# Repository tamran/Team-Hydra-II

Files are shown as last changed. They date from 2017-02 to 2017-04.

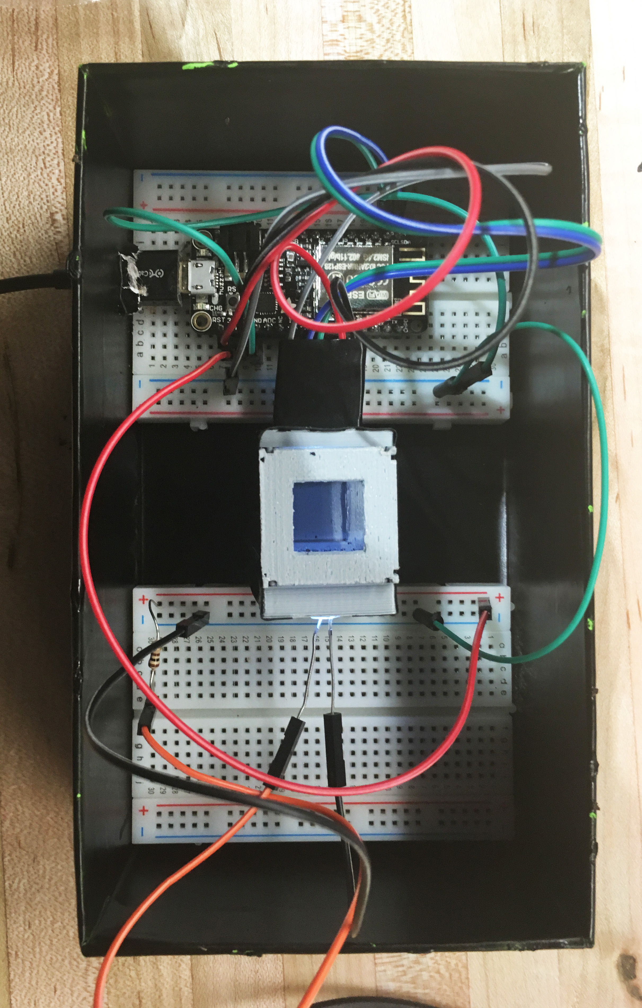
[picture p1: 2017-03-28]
pictures/IMG_0729.png

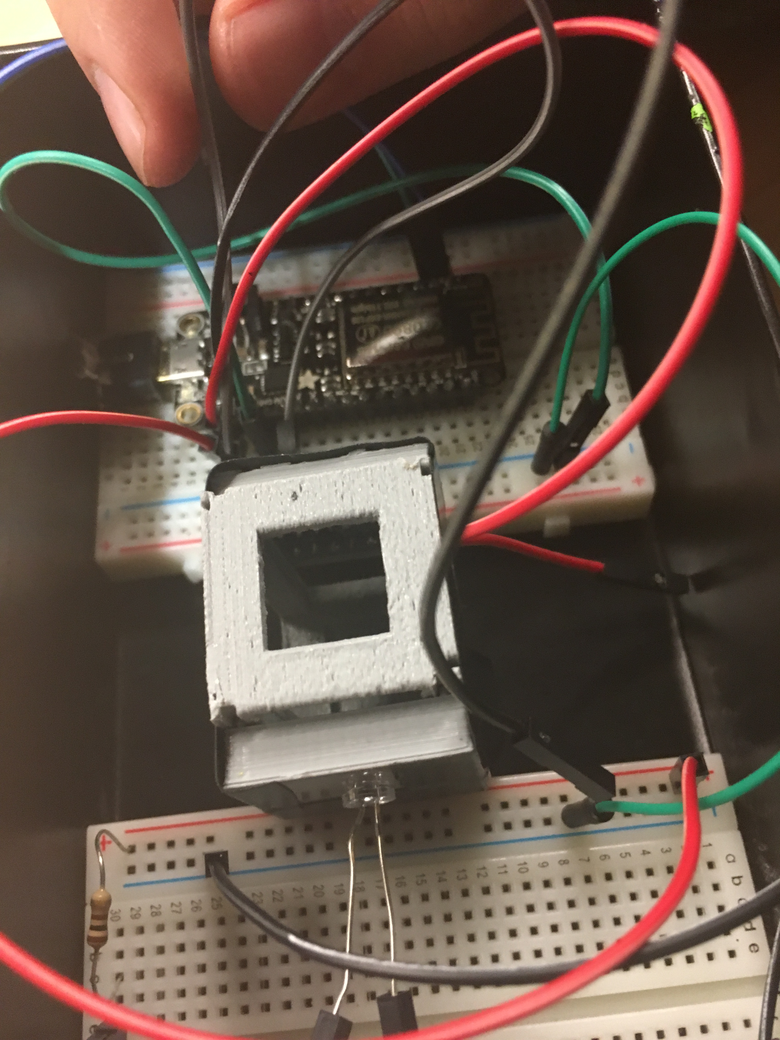
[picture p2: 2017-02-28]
pictures/IMG_0734.JPG

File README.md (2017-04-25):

# Team-Hydra-II

## To access the currently live version of the app:
[Click Here!](https://team-hydra-ii.herokuapp.com/)

## The simplified communication model of this application is:
Application Architecture

## Currently available features on live version:

- From the _web client_
  - Request for a new trial to be started with a given turbidity, concentration, and number of trials
    - __NOTE THAT THE CURRENT MAX NUMBER OF TRIALS IS 30.__ If this number is exceeded, only the first 30 measurements will be posted.
    - This number was chosen as the maximum buffer size that avoids out-of-memory errors
    - _We should run some experiments to see if reducing the measurement frequency will work for our experiments._ If not, we'll need to 1) try to remove any memory leaks in the Arduino code and/or 2) get a microSD for the Feather HUZZAH.
  - View when the last posted measurement was taken
    - __NOTE__ that when the client is first opened, the last posted measurement will be N/A.  When the next measurement is posted to the database, the time will be updated accordingly
  - Clicking the `Experiment Status` navigation item takes you to a page where you can view the new experiment data as it's being added to the database.  This is our equivalent of a "serial monitor." Currently, you can view the Color, Turbidity, and Electrochemical measurements, as they're being taken
  - Clicking the `Trial Data` navigation item displays a list of all conducted Trials.  
    - You can click on the trial name to see all measurements associated with the selected trial.
    - Typing a string into the Filter search box filters the experiments displayed on the screen by the query substring
    - __NOTE__ that the data on this page only updates when you re-select the `Trial Data` navigation item, or when you type a new string
  - Clicking the `Folders` navigation item displays three areas:
    - Create New Folder:
      - Using this field, you can create a new folder in the database
    - Add Trial to Folder:
      - Using this field, you can assoicate a trial in the database with a folder
      - Note that submitting this form will only work correctly if both the folder and trial names already exist in the database
    - Folder Browser:
      - This section displays all folders in the database.  You can filter search for folders.
      - Overall, the purpose of folders is to provide a simple way of associating trials with eachother.  We can mark certain trials as bad by putting them in a "Trash" folder, ect. 

## The server accepts the following API:
  - /
    - `GET` Get the HTML associated with the website
  - /api/newExperiment
    - `GET` Get the information necessary to start running the experiment
      - This is the signal for the sensor to start taking data.  The string will be empty if no experiment is to be run
    - `POST` Inform the server of the information necessary to start running the experiment
      - This API endpoint is intended to be used by the web client
  - /api/clearExperiment
    - `GET` The signal for the sensor to send to the server that it has started to take measurement for the trial specified by /newExperiment
  - /api/trials[?filter=FILTER_STRING]
    - `GET` Returns a string list of the names of all trials stored in the database
      - May optionally filter your request for trials matching a certain string
      - e.g. `/api/trials` returns all trial names
      - e.g. `/api/trials?filter=derp` returns all trials containing the word derp in the trialName
  - /api/trial/:trialName
    - `GET` Returns the measurements associated with the trial :trialName
    - `POST` Creates a trial in the database named :trialName
  - /api/measurement/:type/:trialName
    - `POST` Saves the data stored in the request body to a new measurement in the specified :trialName
      - :type must be one of
        - color
        - turbidity
        - electrochemical
      - When the measurement has been posted to the database, the server notifies the web client that a new measurement has been placed in the database
  - /api/folders[?filter=FILTER_STRING]
    - `GET` returns a string list of the names of all folders stored in the database
  - /api/folder/:folderName
    - `GET` Returns the (unpopulated) Trial objects associated with :folderName
    - `POST` Creates a folder in the database named :folderName
  - /api/folder/:folderName/:trialName
    - `POST` Adds :trialName to the :folderName folder

__NOTE__ that there are two different types of routes - ReactRouter routes, and routes that the server accepts.  For example, there are `/experiment` and `/data` ReactRouter routes that appear when navigating to different tabs on the website. However, reloading the webpage at these routes will result in a _Cannot GET /ROUTE_NAME_.  This is because these are client-side routes only, and thus do not exist on the server side.  I am currently working on a way around this, so that reloading the webpage at one of these routes does not result in the _Cannot GET_ message.

## The (intended) public API available to the Feather

- DataCollection.iso
  - `void collectData(String experiment, int numExperiments)`
    - Takes measurements using the color sensors and the metal rods, and posts the measurements to the database
      - When WiFi isn't available, these measurements are added to a buffer queue, and POSTed when WiFi becomes available again
      - Otherwise, the data is posted as it is collected
      - Note that, in the current setup, each type of measurement is _collected_, but not necessarily _posted_, atomically
        - all of color -> all of turbidity -> all of electrochemical
  - `int createTrial(String trial)`
    - Creates a new trial in the database
    - Returns the HTTP response code (success == 200)
- HTTPRequests.iso
  - `aJsonObject* get(String endpoint)`
    - Makes a GET request to the specified api endpoint
    - Returns the JSON response object
- JSONHelpers.iso
  - `String getField(aJsonObject* json, const char* aField)`
    - Returns the string value of the field in the JSON object
    - Returns "" if the field doesn't exist
  - `aJsonObject* getJson(String response)`
    - Returns the JSON object corresponding to the input string
    - Used to get the JSON object of an HTTP response
  - `aJsonObject* constructMeasurement(const char* R, const char* G, const char* B, const char* C, const char* ColorTemp, const char* lux)`
    - Constructs the JSON object to use as the request for posting a measurement
- WiFiConnector.iso
  - `int connectToWiFi()`
    - Establishes the WiFi connection with our router
    - This command times out after waiting for 5 seconds
    - Returns -1 if could not connect to WiFi, 1 otherwise
    
## Feather Dependencies

In order to run our code, the following packages must be available to the Arduino IDE

- `ESP8266WiFi.h`
- `aJSON.h`
- `ESP8266HTTPClient.h`
- `Adafruit_TCS34725.h`

## Testing Colorimetery *without* the Database
To collect and process colorimetry data **without** pulling from the database, one should run the script `runColorimeter.ino` (under \runColorimeter) in conjunction with the Matlab function `plotCalibData.m.` (under \matlabscripts). 

### Collecting Data
`runColorimeter.ino` allows the Feather to collect *n* data points for each of the color channels. *n* is set in the argument of the function `getColorReading(n)`. Currently *n* is set to 500 but may be modified in the Arduino script. The readings should then be copied from the serial monitor and saved into a text file with the following naming convention: **[type]**Test\_**[val][unit]**.txt where
* **[type]**: 'color' for testing various concentrations; 'turbidity' for testing various turbidities.
* **[val]**: the actual concentration or turbidity of the sample you're testing
* **[unit]**: ppm for concentration, ntu for turbidity

Example: 'colorTest_10ppm.txt'

### Processing in MATLAB
`plotCalibData.m` is a function that analyzes *either* the concentration or turbidity of a set of calibration samples. Given several text files using the naming convention above, it pulls data these text files, and plots the channel measurements against for all of the text files (i.e. samples), and plots the average readings as a function of either concentration or turbidity. The function may be called in the command window of Matlab as follows: `plotCalibData(typeOfTest, values, n)` where
* **typeOfTest**: 'color' if you are analyzing calibration samples of different concentrations; 'turbidity' if you are analyzing calibration samples of different turbidities.
* **values**: vector of concentrations or turbidities you would like to analyze. (e.g. [1, 10, 20, 30, 40] where each number represents the concentration in ppm)
* **n**: number of data points contained in each sample trial/text file.

## To setup the Feather communication in Arduino:

- host = team-hydra-ii.herokuapp.com
- httpPort = 80
- Check for a new measurement
  - Make a GET request to /api/newMeasurement
  - If the response has a body (i.e. is not {})
    - Make a POST request to /api/trial/:trialName (where :trialName is the `experimentName` field in the response body of the previous GET request) to create a new trial called :trialName in the database
    - The number of times to run the experiment is specified in the response body of the GET request, in the field `numExperiments`
    - For each measurement that you take, make a POST request to /api/measurement/color/:trialName, where the body of the post request contains all of the measurement information
    - Once the requested number of measurements have been taken, make a GET request to /api/clearExperiment to clear the requested experiment that you just completed
    
## To communicate with the API over command line:

- To create a new experiment:
  - Go to the website, fill out the form, and press enter
- To view the new experiment that is created by the form on the website:
  - `curl team-hydra-ii.herokuapp.com/api/newExperiment`
- To create a new trial in the database:
  - `curl --data "" team-hydra-ii.herokuapp.com/api/trial/TRIALNAME`
- To add a measurement to this trial name:
  - `curl --data "R=2&G=3&B=4&C=5&ColorTemp=6&lux=7" team-hydra-ii.herokuapp.com/api/measurement/color/TRIALNAME`
- To clear the new experiment flag once the experiment has completed:
  - `curl team-hydra-ii.herokuapp.com/api/clearExperiment`

## To setup the Express Server on a local machine:

- First, you'll need to install [NodeJS](https://nodejs.org/en/)
- Navigate to the base directory of the Team-Hydra-II project
- Type `npm install` to install all dependencies listed in `package.json`

## To start the app locally:

- Run `npm run watch` to transpile the client-side code into a form that can be rendered in a browser
- Run `npm run serve` to start the development server
  - **Important** this command will __fail__ unless you have initialized the MONGODB_URI environment variable
  - I have intentionally hidden this, as keeping this under version control is *very* bad practice (for obvious reasons).
  - If you need to run this server in development, let me know, and I'll give you access to this URI
- To open the app locally, go to a browser and visit `localhost:3000`.
- The setup allows continuous development without re-running code!
  - __Note__ that when you make changes to files in the `server/` directory, the server will automatically be restarted with nodemon.   When you change code in the `src/` directory, the code will be re-transpiled with watchify and babelify

## To prepare the app for production:
- Run `npm run build`
  - This builds a production-ready, transpiled server and client code that can be run on Heroku. 
  - This is necessary, as I'm using new JavaScript syntax, and node does not currently support all of its features
- Commit/push all changes, then upload to Heroku using `git push heroku master`
- You can then visit the live website by typing `heroku open` in terminal

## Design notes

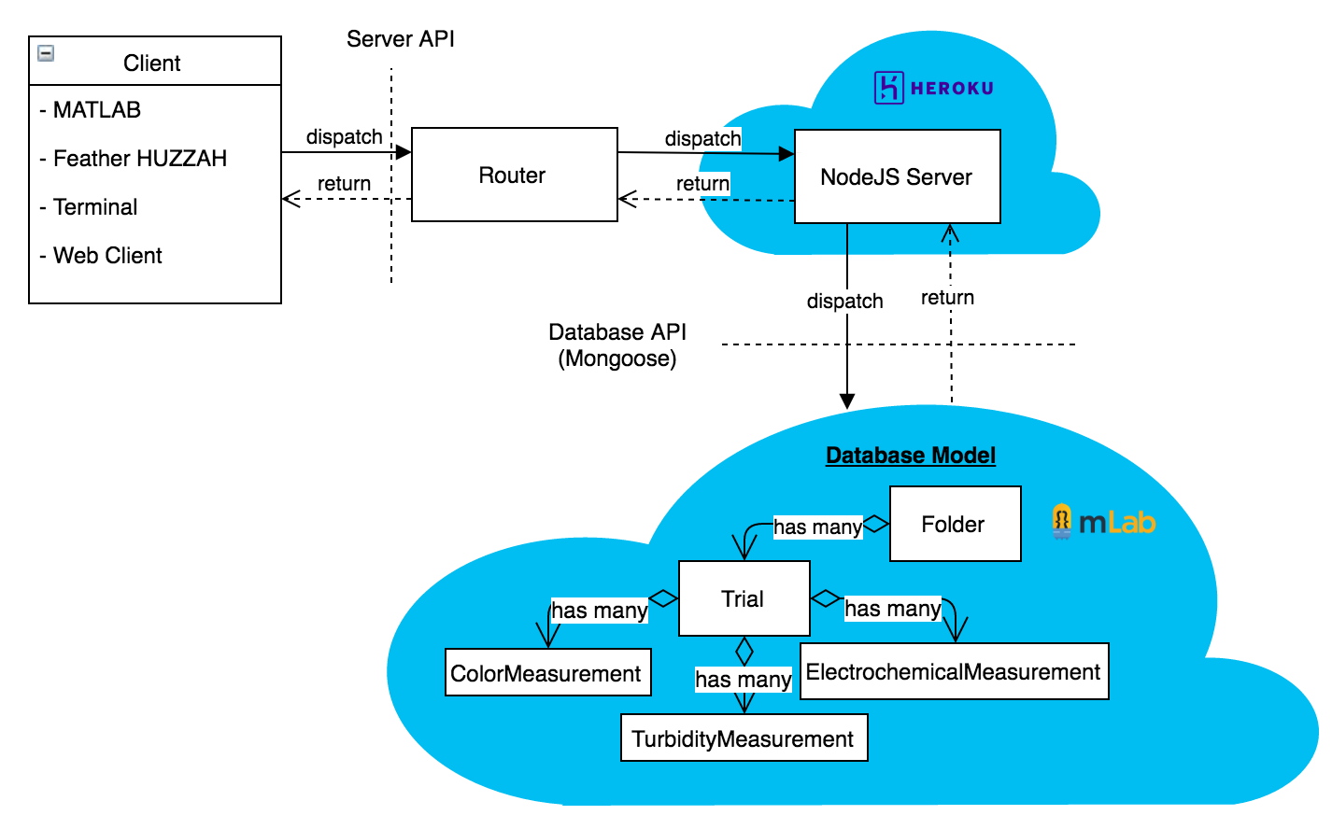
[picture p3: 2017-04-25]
diagrams/UpdateAppArchitecture2.png

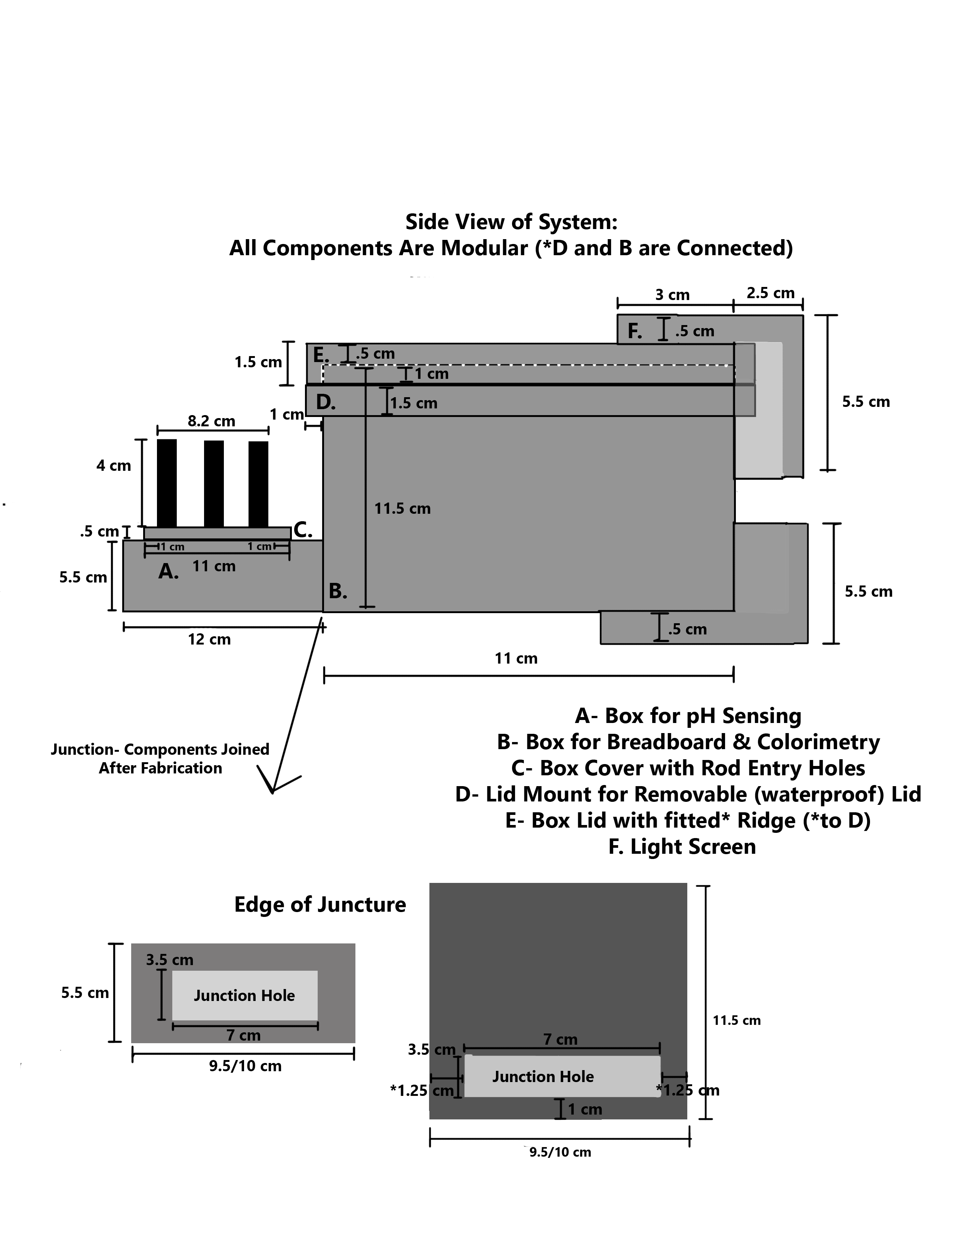
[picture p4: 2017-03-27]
PhotoshopFiles/GeneralCasingDesign.png

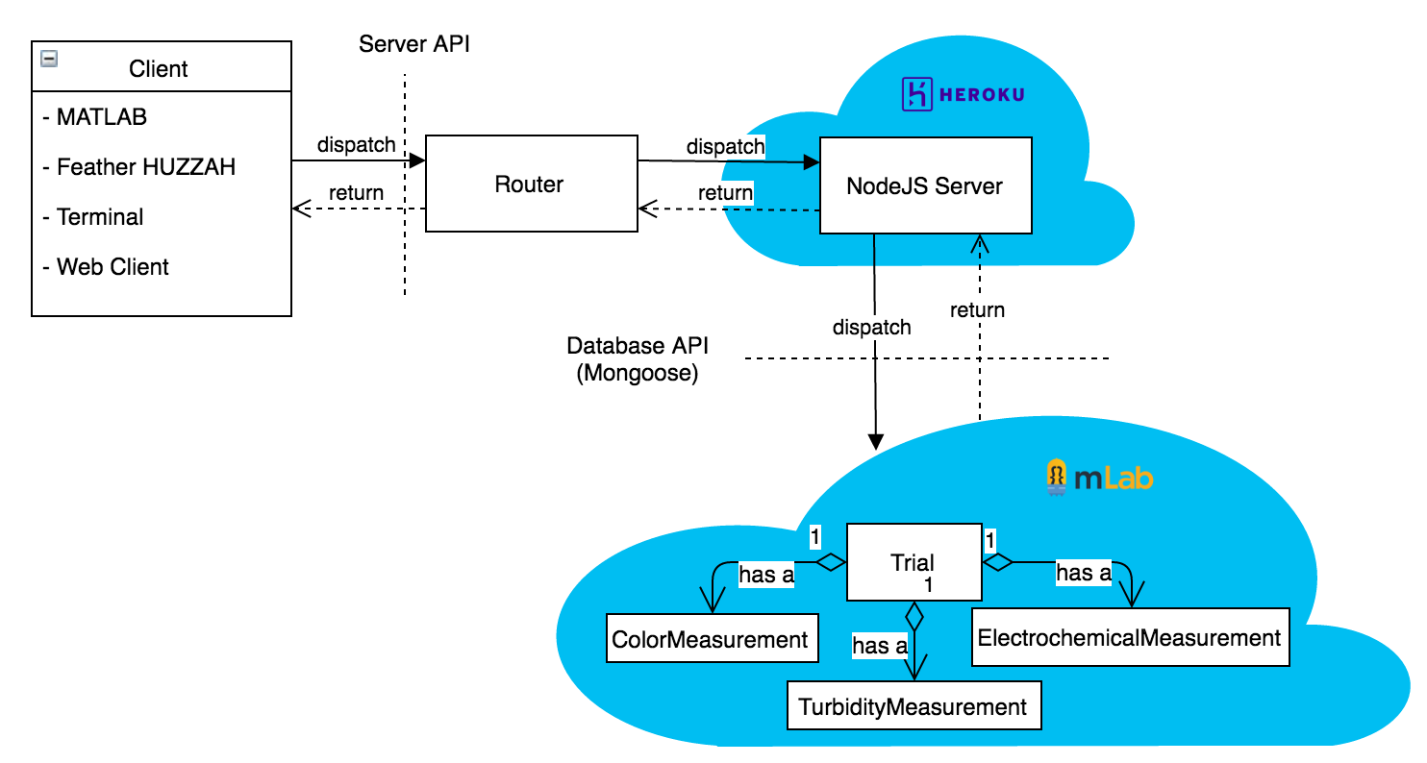
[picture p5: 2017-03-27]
diagrams/AppArchitecture.png

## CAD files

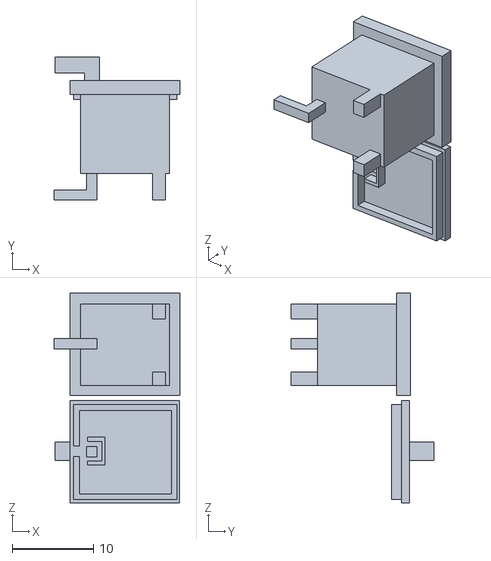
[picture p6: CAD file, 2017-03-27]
autocad_files/ColorimeterModel.stl
15.5 x 17.6 x 25.9

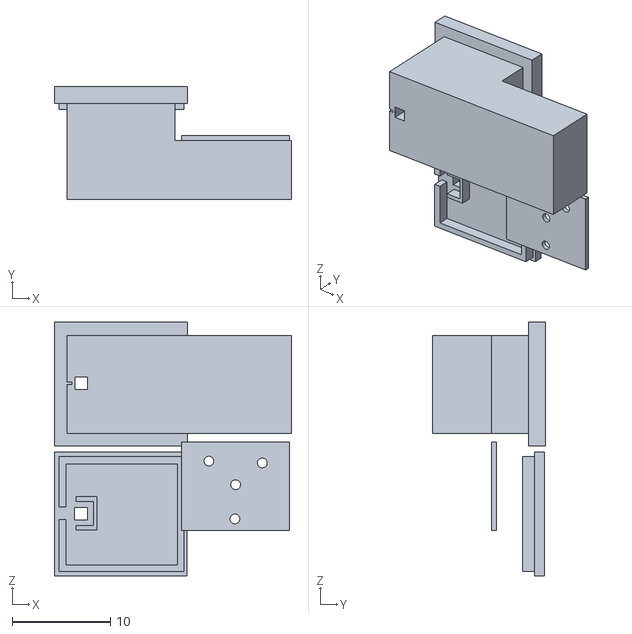
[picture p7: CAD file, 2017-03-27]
autocad_files/PrototypeMarch21.stl
24.2 x 11.5 x 25.9

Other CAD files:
autocad_files/SensorHolder.dwg
autocad_files/LEDHolder.dwg
autocad_files/SampleHolder.dwg

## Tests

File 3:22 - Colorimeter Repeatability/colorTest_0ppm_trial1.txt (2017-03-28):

Color Temp: 17456 K - Lux: 2768 - R: 3915 G: 5235 B: 5770 C: 15007  
Color Temp: 17512 K - Lux: 2765 - R: 3914 G: 5234 B: 5772 C: 15007  
Color Temp: 17532 K - Lux: 2765 - R: 3913 G: 5234 B: 5773 C: 15008  
Color Temp: 17550 K - Lux: 2764 - R: 3913 G: 5234 B: 5774 C: 15009  
Color Temp: 17552 K - Lux: 2764 - R: 3912 G: 5233 B: 5773 C: 15006  
Color Temp: 17570 K - Lux: 2764 - R: 3912 G: 5234 B: 5775 C: 15009  
Color Temp: 17570 K - Lux: 2764 - R: 3912 G: 5234 B: 5775 C: 15008  
Color Temp: 17593 K - Lux: 2762 - R: 3910 G: 5232 B: 5774 C: 15003  
Color Temp: 17607 K - Lux: 2762 - R: 3912 G: 5233 B: 5776 C: 15008  
Color Temp: 17609 K - Lux: 2762 - R: 3911 G: 5233 B: 5776 C: 15008  
Color Temp: 17606 K - Lux: 2762 - R: 3912 G: 5234 B: 5777 C: 15010  
Color Temp: 17609 K - Lux: 2762 - R: 3911 G: 5233 B: 5776 C: 15008  
Color Temp: 17624 K - Lux: 2762 - R: 3912 G: 5234 B: 5778 C: 15012  
Color Temp: 17624 K - Lux: 2762 - R: 3912 G: 5235 B: 5779 C: 15014  
Color Temp: 17624 K - Lux: 2762 - R: 3912 G: 5234 B: 5778 C: 15011  
Color Temp: 17627 K - Lux: 2761 - R: 3911 G: 5233 B: 5777 C: 15009  
Color Temp: 17650 K - Lux: 2759 - R: 3909 G: 5231 B: 5776 C: 15003  
Color Temp: 17650 K - Lux: 2759 - R: 3909 G: 5231 B: 5776 C: 15003  
Color Temp: 17652 K - Lux: 2759 - R: 3908 G: 5230 B: 5775 C: 15001  
Color Temp: 17655 K - Lux: 2757 - R: 3907 G: 5228 B: 5773 C: 14997  
Color Temp: 17655 K - Lux: 2757 - R: 3907 G: 5228 B: 5773 C: 14997  
Color Temp: 17653 K - Lux: 2758 - R: 3908 G: 5229 B: 5774 C: 14999  
Color Temp: 17671 K - Lux: 2757 - R: 3908 G: 5229 B: 5775 C: 15000  
Color Temp: 17673 K - Lux: 2757 - R: 3907 G: 5228 B: 5774 C: 14997  
Color Temp: 17655 K - Lux: 2757 - R: 3907 G: 5228 B: 5773 C: 14996  
Color Temp: 17670 K - Lux: 2758 - R: 3908 G: 5230 B: 5776 C: 15001  
Color Temp: 17673 K - Lux: 2757 - R: 3907 G: 5228 B: 5774 C: 14997  
Color Temp: 17654 K - Lux: 2758 - R: 3907 G: 5229 B: 5774 C: 14997  
Color Temp: 17676 K - Lux: 2756 - R: 3906 G: 5227 B: 5773 C: 14992  
Color Temp: 17657 K - Lux: 2758 - R: 3906 G: 5228 B: 5773 C: 14993  
Color Temp: 17673 K - Lux: 2757 - R: 3907 G: 5228 B: 5774 C: 14995  
Color Temp: 17676 K - Lux: 2756 - R: 3906 G: 5227 B: 5773 C: 14992  
Color Temp: 17678 K - Lux: 2756 - R: 3905 G: 5226 B: 5772 C: 14989  
Color Temp: 17680 K - Lux: 2755 - R: 3904 G: 5225 B: 5771 C: 14985  
Color Temp: 17686 K - Lux: 2753 - R: 3902 G: 5222 B: 5768 C: 14978  
Color Temp: 17688 K - Lux: 2753 - R: 3901 G: 5221 B: 5767 C: 14976  
Color Temp: 17696 K - Lux: 2755 - R: 3905 G: 5226 B: 5773 C: 14991  
Color Temp: 17696 K - Lux: 2755 - R: 3905 G: 5226 B: 5773 C: 14992  
Color Temp: 17688 K - Lux: 2753 - R: 3901 G: 5221 B: 5767 C: 14976  
Color Temp: 17691 K - Lux: 2751 - R: 3900 G: 5219 B: 5765 C: 14971  
Color Temp: 17712 K - Lux: 2750 - R: 3899 G: 5218 B: 5765 C: 14969  
Color Temp: 17693 K - Lux: 2752 - R: 3899 G: 5219 B: 5765 C: 14970  
Color Temp: 17709 K - Lux: 2751 - R: 3900 G: 5219 B: 5766 C: 14972  
Color Temp: 17711 K - Lux: 2751 - R: 3899 G: 5219 B: 5766 C: 14971  
Color Temp: 17693 K - Lux: 2752 - R: 3899 G: 5219 B: 5765 C: 14970  
Color Temp: 17709 K - Lux: 2751 - R: 3900 G: 5220 B: 5767 C: 14974  
Color Temp: 17712 K - Lux: 2750 - R: 3899 G: 5218 B: 5765 C: 14969  
Color Temp: 17695 K - Lux: 2751 - R: 3898 G: 5218 B: 5764 C: 14967  
Color Temp: 17715 K - Lux: 2749 - R: 3898 G: 5216 B: 5763 C: 14964  
Color Temp: 17701 K - Lux: 2749 - R: 3896 G: 5215 B: 5761 C: 14960  
Color Temp: 17701 K - Lux: 2748 - R: 3896 G: 5214 B: 5760 C: 14958  
Color Temp: 17719 K - Lux: 2748 - R: 3896 G: 5214 B: 5761 C: 14957  
Color Temp: 17708 K - Lux: 2747 - R: 3893 G: 5211 B: 5757 C: 14947  
Color Temp: 17711 K - Lux: 2746 - R: 3892 G: 5210 B: 5756 C: 14945  
Color Temp: 17692 K - Lux: 2747 - R: 3892 G: 5210 B: 5755 C: 14943  
Color Temp: 17695 K - Lux: 2747 - R: 3891 G: 5209 B: 5754 C: 14940  
Color Temp: 17713 K - Lux: 2746 - R: 3891 G: 5209 B: 5755 C: 14940  
Color Temp: 17713 K - Lux: 2746 - R: 3891 G: 5209 B: 5755 C: 14940  
Color Temp: 17708 K - Lux: 2748 - R: 3893 G: 5212 B: 5758 C: 14947  
Color Temp: 17727 K - Lux: 2746 - R: 3893 G: 5211 B: 5758 C: 14946  
Color Temp: 17727 K - Lux: 2745 - R: 3893 G: 5210 B: 5757 C: 14945  
Color Temp: 17711 K - Lux: 2746 - R: 3892 G: 5209 B: 5755 C: 14942  
Color Temp: 17713 K - Lux: 2746 - R: 3891 G: 5209 B: 5755 C: 14941  
Color Temp: 17710 K - Lux: 2747 - R: 3892 G: 5211 B: 5757 C: 14945  
Color Temp: 17711 K - Lux: 2746 - R: 3892 G: 5210 B: 5756 C: 14944  
Color Temp: 17713 K - Lux: 2746 - R: 3891 G: 5209 B: 5755 C: 14941  
Color Temp: 17718 K - Lux: 2745 - R: 3889 G: 5207 B: 5753 C: 14936  
Color Temp: 17724 K - Lux: 2742 - R: 3887 G: 5203 B: 5749 C: 14925  
Color Temp: 17710 K - Lux: 2742 - R: 3885 G: 5201 B: 5746 C: 14918  
Color Temp: 17713 K - Lux: 2740 - R: 3884 G: 5199 B: 5744 C: 14913  
Color Temp: 17705 K - Lux: 2738 - R: 3880 G: 5194 B: 5738 C: 14900  
Color Temp: 17710 K - Lux: 2736 - R: 3878 G: 5191 B: 5735 C: 14893  
Color Temp: 17715 K - Lux: 2735 - R: 3876 G: 5189 B: 5733 C: 14886  
Color Temp: 17739 K - Lux: 2733 - R: 3874 G: 5186 B: 5731 C: 14879  
Color Temp: 17742 K - Lux: 2731 - R: 3873 G: 5184 B: 5729 C: 14874  
Color Temp: 17744 K - Lux: 2731 - R: 3872 G: 5183 B: 5728 C: 14871  
Color Temp: 17744 K - Lux: 2731 - R: 3872 G: 5183 B: 5728 C: 14871  
Color Temp: 17728 K - Lux: 2731 - R: 3871 G: 5182 B: 5726 C: 14865  
Color Temp: 17731 K - Lux: 2730 - R: 3870 G: 5180 B: 5724 C: 14859  
Color Temp: 17736 K - Lux: 2729 - R: 3868 G: 5178 B: 5722 C: 14855  
Color Temp: 17739 K - Lux: 2727 - R: 3867 G: 5176 B: 5720 C: 14850  
Color Temp: 17723 K - Lux: 2727 - R: 3866 G: 5175 B: 5718 C: 14846  
Color Temp: 17744 K - Lux: 2725 - R: 3865 G: 5173 B: 5717 C: 14842  
Color Temp: 17749 K - Lux: 2724 - R: 3863 G: 5171 B: 5715 C: 14836  
Color Temp: 17731 K - Lux: 2725 - R: 3863 G: 5171 B: 5714 C: 14834  
Color Temp: 17733 K - Lux: 2724 - R: 3862 G: 5170 B: 5713 C: 14831  
Color Temp: 17733 K - Lux: 2724 - R: 3862 G: 5170 B: 5713 C: 14831  
Color Temp: 17736 K - Lux: 2724 - R: 3861 G: 5169 B: 5712 C: 14829  
Color Temp: 17741 K - Lux: 2722 - R: 3859 G: 5166 B: 5709 C: 14820  
Color Temp: 17743 K - Lux: 2722 - R: 3858 G: 5165 B: 5708 C: 14818  
Color Temp: 17744 K - Lux: 2721 - R: 3858 G: 5164 B: 5707 C: 14815  
Color Temp: 17749 K - Lux: 2720 - R: 3856 G: 5162 B: 5705 C: 14808  
Color Temp: 17733 K - Lux: 2720 - R: 3855 G: 5161 B: 5703 C: 14804  
Color Temp: 17737 K - Lux: 2719 - R: 3853 G: 5159 B: 5701 C: 14798  
Color Temp: 17738 K - Lux: 2718 - R: 3853 G: 5158 B: 5700 C: 14796  
Color Temp: 17740 K - Lux: 2717 - R: 3852 G: 5157 B: 5699 C: 14793  
Color Temp: 17724 K - Lux: 2718 - R: 3851 G: 5156 B: 5697 C: 14788  
Color Temp: 17751 K - Lux: 2714 - R: 3848 G: 5152 B: 5694 C: 14779  
Color Temp: 17737 K - Lux: 2714 - R: 3846 G: 5150 B: 5691 C: 14772  
Color Temp: 17742 K - Lux: 2712 - R: 3844 G: 5147 B: 5688 C: 14765  
Color Temp: 17745 K - Lux: 2711 - R: 3843 G: 5145 B: 5686 C: 14760  
Color Temp: 17748 K - Lux: 2710 - R: 3842 G: 5143 B: 5684 C: 14754  
Color Temp: 17751 K - Lux: 2709 - R: 3841 G: 5142 B: 5683 C: 14750  
Color Temp: 17772 K - Lux: 2708 - R: 3840 G: 5141 B: 5683 C: 14749  
Color Temp: 17736 K - Lux: 2710 - R: 3839 G: 5141 B: 5681 C: 14746  
Color Temp: 17734 K - Lux: 2710 - R: 3840 G: 5142 B: 5682 C: 14749  
Color Temp: 17756 K - Lux: 2708 - R: 3839 G: 5140 B: 5681 C: 14745  
Color Temp: 17756 K - Lux: 2708 - R: 3839 G: 5140 B: 5681 C: 14746  
Color Temp: 17756 K - Lux: 2708 - R: 3839 G: 5140 B: 5681 C: 14746  
Color Temp: 17753 K - Lux: 2708 - R: 3840 G: 5141 B: 5682 C: 14749  
Color Temp: 17751 K - Lux: 2709 - R: 3841 G: 5142 B: 5683 C: 14751  
Color Temp: 17751 K - Lux: 2709 - R: 3841 G: 5142 B: 5683 C: 14751  
Color Temp: 17734 K - Lux: 2710 - R: 3840 G: 5142 B: 5682 C: 14749  
Color Temp: 17734 K - Lux: 2710 - R: 3840 G: 5142 B: 5682 C: 14749  
Color Temp: 17742 K - Lux: 2708 - R: 3837 G: 5138 B: 5678 C: 14738  
Color Temp: 17742 K - Lux: 2708 - R: 3837 G: 5138 B: 5678 C: 14738  
Color Temp: 17745 K - Lux: 2706 - R: 3836 G: 5136 B: 5676 C: 14733  
Color Temp: 17729 K - Lux: 2707 - R: 3835 G: 5135 B: 5674 C: 14728  
Color Temp: 17731 K - Lux: 2706 - R: 3834 G: 5134 B: 5673 C: 14726  
Color Temp: 17753 K - Lux: 2704 - R: 3833 G: 5132 B: 5672 C: 14723  
Color Temp: 17753 K - Lux: 2704 - R: 3833 G: 5132 B: 5672 C: 14722  
Color Temp: 17753 K - Lux: 2703 - R: 3833 G: 5131 B: 5671 C: 14721  
Color Temp: 17758 K - Lux: 2702 - R: 3831 G: 5129 B: 5669 C: 14715  
Color Temp: 17760 K - Lux: 2702 - R: 3830 G: 5129 B: 5669 C: 14713  
Color Temp: 17763 K - Lux: 2701 - R: 3829 G: 5127 B: 5667 C: 14708  
Color Temp: 17763 K - Lux: 2701 - R: 3829 G: 5127 B: 5667 C: 14708  
Color Temp: 17761 K - Lux: 2701 - R: 3830 G: 5128 B: 5668 C: 14710  
Color Temp: 17763 K - Lux: 2701 - R: 3829 G: 5127 B: 5667 C: 14708  
Color Temp: 17761 K - Lux: 2701 - R: 3830 G: 5128 B: 5668 C: 14710  
Color Temp: 17739 K - Lux: 2704 - R: 3831 G: 5130 B: 5669 C: 14716  
Color Temp: 17758 K - Lux: 2703 - R: 3831 G: 5130 B: 5670 C: 14716  
Color Temp: 17761 K - Lux: 2701 - R: 3830 G: 5128 B: 5668 C: 14711  
Color Temp: 17750 K - Lux: 2700 - R: 3827 G: 5124 B: 5663 C: 14698  
Color Temp: 17755 K - Lux: 2698 - R: 3825 G: 5121 B: 5660 C: 14690  
Color Temp: 17760 K - Lux: 2697 - R: 3823 G: 5119 B: 5658 C: 14685  
Color Temp: 17761 K - Lux: 2696 - R: 3823 G: 5118 B: 5657 C: 14683  
Color Temp: 17761 K - Lux: 2696 - R: 3823 G: 5118 B: 5657 C: 14683  
Color Temp: 17766 K - Lux: 2695 - R: 3821 G: 5116 B: 5655 C: 14677  
Color Temp: 17766 K - Lux: 2695 - R: 3821 G: 5116 B: 5655 C: 14676  
Color Temp: 17755 K - Lux: 2698 - R: 3825 G: 5121 B: 5660 C: 14692  
Color Temp: 17764 K - Lux: 2706 - R: 3836 G: 5136 B: 5677 C: 14735  
Color Temp: 17764 K - Lux: 2706 - R: 3836 G: 5136 B: 5677 C: 14734  
Color Temp: 17772 K - Lux: 2712 - R: 3847 G: 5150 B: 5693 C: 14775  
Color Temp: 17756 K - Lux: 2713 - R: 3846 G: 5150 B: 5692 C: 14774  
Color Temp: 17772 K - Lux: 2712 - R: 3847 G: 5150 B: 5693 C: 14775  
Color Temp: 17758 K - Lux: 2713 - R: 3845 G: 5149 B: 5691 C: 14770  
Color Temp: 17759 K - Lux: 2712 - R: 3845 G: 5148 B: 5690 C: 14767  
Color Temp: 17764 K - Lux: 2711 - R: 3843 G: 5146 B: 5688 C: 14762  
Color Temp: 17767 K - Lux: 2710 - R: 3842 G: 5144 B: 5686 C: 14757  
Color Temp: 17755 K - Lux: 2709 - R: 3839 G: 5141 B: 5682 C: 14748  
Color Temp: 17747 K - Lux: 2706 - R: 3835 G: 5135 B: 5675 C: 14730  
Color Temp: 17755 K - Lux: 2704 - R: 3832 G: 5132 B: 5672 C: 14722  
Color Temp: 17774 K - Lux: 2703 - R: 3832 G: 5131 B: 5672 C: 14720  
Color Temp: 17757 K - Lux: 2704 - R: 3831 G: 5131 B: 5671 C: 14717  
Color Temp: 17758 K - Lux: 2703 - R: 3831 G: 5130 B: 5670 C: 14717  
Color Temp: 17758 K - Lux: 2703 - R: 3831 G: 5130 B: 5670 C: 14716  
Color Temp: 17777 K - Lux: 2701 - R: 3831 G: 5129 B: 5670 C: 14714  
Color Temp: 17758 K - Lux: 2702 - R: 3831 G: 5129 B: 5669 C: 14714  
Color Temp: 17760 K - Lux: 2702 - R: 3830 G: 5129 B: 5669 C: 14714  
Color Temp: 17763 K - Lux: 2701 - R: 3829 G: 5127 B: 5667 C: 14707  
Color Temp: 17763 K - Lux: 2702 - R: 3829 G: 5128 B: 5668 C: 14707  
Color Temp: 17763 K - Lux: 2701 - R: 3829 G: 5127 B: 5667 C: 14706  
Color Temp: 17746 K - Lux: 2702 - R: 3828 G: 5127 B: 5666 C: 14704  
Color Temp: 17730 K - Lux: 2702 - R: 3827 G: 5126 B: 5664 C: 14701  
Color Temp: 17752 K - Lux: 2700 - R: 3826 G: 5124 B: 5663 C: 14697  
Color Temp: 17771 K - Lux: 2699 - R: 3826 G: 5123 B: 5663 C: 14698  
Color Temp: 17769 K - Lux: 2699 - R: 3827 G: 5124 B: 5664 C: 14700  
Color Temp: 17766 K - Lux: 2700 - R: 3828 G: 5126 B: 5666 C: 14705  
Color Temp: 17760 K - Lux: 2702 - R: 3830 G: 5129 B: 5669 C: 14712  
Color Temp: 17755 K - Lux: 2703 - R: 3832 G: 5131 B: 5671 C: 14718  
Color Temp: 17755 K - Lux: 2704 - R: 3832 G: 5132 B: 5672 C: 14721  
Color Temp: 17752 K - Lux: 2705 - R: 3833 G: 5133 B: 5673 C: 14722  
Color Temp: 17752 K - Lux: 2705 - R: 3833 G: 5133 B: 5673 C: 14723  
Color Temp: 17752 K - Lux: 2705 - R: 3833 G: 5133 B: 5673 C: 14723  
Color Temp: 17755 K - Lux: 2704 - R: 3832 G: 5132 B: 5672 C: 14720  
Color Temp: 17772 K - Lux: 2703 - R: 3833 G: 5132 B: 5673 C: 14722  
Color Temp: 17771 K - Lux: 2704 - R: 3833 G: 5133 B: 5674 C: 14725  
Color Temp: 17766 K - Lux: 2705 - R: 3835 G: 5135 B: 5676 C: 14729  
Color Temp: 17766 K - Lux: 2705 - R: 3835 G: 5135 B: 5676 C: 14729  
Color Temp: 17747 K - Lux: 2707 - R: 3835 G: 5136 B: 5676 C: 14730  
Color Temp: 17763 K - Lux: 2706 - R: 3836 G: 5137 B: 5678 C: 14735  
Color Temp: 17761 K - Lux: 2707 - R: 3837 G: 5138 B: 5679 C: 14737  
Color Temp: 17758 K - Lux: 2707 - R: 3838 G: 5139 B: 5680 C: 14742  
Color Temp: 17778 K - Lux: 2706 - R: 3838 G: 5138 B: 5680 C: 14743  
Color Temp: 17759 K - Lux: 2707 - R: 3838 G: 5138 B: 5679 C: 14742  
Color Temp: 17779 K - Lux: 2706 - R: 3837 G: 5138 B: 5680 C: 14740  
Color Temp: 17778 K - Lux: 2706 - R: 3838 G: 5138 B: 5680 C: 14743  
Color Temp: 17758 K - Lux: 2707 - R: 3838 G: 5139 B: 5680 C: 14742  
Color Temp: 17761 K - Lux: 2707 - R: 3837 G: 5138 B: 5679 C: 14739  
Color Temp: 17764 K - Lux: 2706 - R: 3836 G: 5136 B: 5677 C: 14735  
Color Temp: 17785 K - Lux: 2703 - R: 3835 G: 5134 B: 5676 C: 14732  
Color Temp: 17767 K - Lux: 2704 - R: 3835 G: 5134 B: 5675 C: 14731  
Color Temp: 17788 K - Lux: 2703 - R: 3834 G: 5133 B: 5675 C: 14730  
Color Temp: 17772 K - Lux: 2703 - R: 3833 G: 5132 B: 5673 C: 14724  
Color Temp: 17755 K - Lux: 2703 - R: 3832 G: 5131 B: 5671 C: 14720  
Color Temp: 17763 K - Lux: 2702 - R: 3829 G: 5128 B: 5668 C: 14711  
Color Temp: 17780 K - Lux: 2701 - R: 3830 G: 5128 B: 5669 C: 14712  
Color Temp: 17780 K - Lux: 2701 - R: 3830 G: 5128 B: 5669 C: 14711  
Color Temp: 17780 K - Lux: 2701 - R: 3830 G: 5128 B: 5669 C: 14712  
Color Temp: 17781 K - Lux: 2701 - R: 3829 G: 5128 B: 5669 C: 14711  
Color Temp: 17782 K - Lux: 2700 - R: 3829 G: 5127 B: 5668 C: 14708  
Color Temp: 17763 K - Lux: 2702 - R: 3829 G: 5128 B: 5668 C: 14708  
Color Temp: 17766 K - Lux: 2700 - R: 3828 G: 5126 B: 5666 C: 14703  
Color Temp: 17768 K - Lux: 2700 - R: 3827 G: 5125 B: 5665 C: 14702  
Color Temp: 17771 K - Lux: 2699 - R: 3826 G: 5123 B: 5663 C: 14697  
Color Temp: 17752 K - Lux: 2700 - R: 3826 G: 5124 B: 5663 C: 14697  
Color Temp: 17754 K - Lux: 2700 - R: 3825 G: 5123 B: 5662 C: 14695  
Color Temp: 17776 K - Lux: 2697 - R: 3824 G: 5121 B: 5661 C: 14691  
Color Temp: 17774 K - Lux: 2698 - R: 3825 G: 5122 B: 5662 C: 14693  
Color Temp: 17791 K - Lux: 2697 - R: 3826 G: 5122 B: 5663 C: 14696  
Color Temp: 17774 K - Lux: 2698 - R: 3825 G: 5122 B: 5662 C: 14694  
Color Temp: 17752 K - Lux: 2699 - R: 3826 G: 5123 B: 5662 C: 14696  
Color Temp: 17774 K - Lux: 2698 - R: 3825 G: 5122 B: 5662 C: 14694  
Color Temp: 17755 K - Lux: 2699 - R: 3825 G: 5122 B: 5661 C: 14694  
Color Temp: 17755 K - Lux: 2699 - R: 3825 G: 5122 B: 5661 C: 14693  
Color Temp: 17774 K - Lux: 2698 - R: 3825 G: 5122 B: 5662 C: 14696  
Color Temp: 17774 K - Lux: 2698 - R: 3825 G: 5122 B: 5662 C: 14695  
Color Temp: 17793 K - Lux: 2696 - R: 3825 G: 5121 B: 5662 C: 14693  
Color Temp: 17776 K - Lux: 2697 - R: 3824 G: 5121 B: 5661 C: 14691  
Color Temp: 17779 K - Lux: 2696 - R: 3823 G: 5119 B: 5659 C: 14687  
Color Temp: 17799 K - Lux: 2695 - R: 3823 G: 5118 B: 5659 C: 14685  
Color Temp: 17779 K - Lux: 2697 - R: 3823 G: 5120 B: 5660 C: 14688  
Color Temp: 17796 K - Lux: 2696 - R: 3824 G: 5120 B: 5661 C: 14690  
Color Temp: 17774 K - Lux: 2698 - R: 3825 G: 5122 B: 5662 C: 14693  
Color Temp: 17773 K - Lux: 2699 - R: 3825 G: 5123 B: 5663 C: 14696  
Color Temp: 17774 K - Lux: 2698 - R: 3825 G: 5122 B: 5662 C: 14694  
Color Temp: 17793 K - Lux: 2696 - R: 3825 G: 5121 B: 5662 C: 14693  
Color Temp: 17774 K - Lux: 2698 - R: 3825 G: 5122 B: 5662 C: 14695  
Color Temp: 17773 K - Lux: 2699 - R: 3825 G: 5123 B: 5663 C: 14697  
Color Temp: 17771 K - Lux: 2699 - R: 3826 G: 5123 B: 5663 C: 14698  
Color Temp: 17787 K - Lux: 2699 - R: 3827 G: 5125 B: 5666 C: 14704  
Color Temp: 17766 K - Lux: 2700 - R: 3828 G: 5126 B: 5666 C: 14705  
Color Temp: 17782 K - Lux: 2700 - R: 3829 G: 5127 B: 5668 C: 14709  
Color Temp: 17763 K - Lux: 2702 - R: 3829 G: 5128 B: 5668 C: 14711  
Color Temp: 17778 K - Lux: 2702 - R: 3830 G: 5130 B: 5671 C: 14716  
Color Temp: 17774 K - Lux: 2703 - R: 3832 G: 5132 B: 5673 C: 14723  
Color Temp: 17774 K - Lux: 2703 - R: 3832 G: 5132 B: 5673 C: 14723  
Color Temp: 17790 K - Lux: 2702 - R: 3833 G: 5132 B: 5674 C: 14725  
Color Temp: 17790 K - Lux: 2703 - R: 3833 G: 5133 B: 5675 C: 14727  
Color Temp: 17785 K - Lux: 2704 - R: 3835 G: 5135 B: 5677 C: 14732  
Color Temp: 17787 K - Lux: 2705 - R: 3834 G: 5135 B: 5677 C: 14730  
Color Temp: 17787 K - Lux: 2704 - R: 3834 G: 5134 B: 5676 C: 14729  
Color Temp: 17771 K - Lux: 2704 - R: 3833 G: 5133 B: 5674 C: 14724  
Color Temp: 17790 K - Lux: 2702 - R: 3833 G: 5132 B: 5674 C: 14725  
Color Temp: 17771 K - Lux: 2704 - R: 3833 G: 5133 B: 5674 C: 14725  
Color Temp: 17776 K - Lux: 2703 - R: 3831 G: 5131 B: 5672 C: 14719  
Color Temp: 17776 K - Lux: 2703 - R: 3831 G: 5131 B: 5672 C: 14720  
Color Temp: 17777 K - Lux: 2702 - R: 3831 G: 5130 B: 5671 C: 14717  
Color Temp: 17781 K - Lux: 2701 - R: 3829 G: 5128 B: 5669 C: 14710  
Color Temp: 17784 K - Lux: 2701 - R: 3828 G: 5127 B: 5668 C: 14707  
Color Temp: 17784 K - Lux: 2700 - R: 3828 G: 5126 B: 5667 C: 14706  
Color Temp: 17784 K - Lux: 2701 - R: 3828 G: 5127 B: 5668 C: 14708  
Color Temp: 17784 K - Lux: 2700 - R: 3828 G: 5126 B: 5667 C: 14706  
Color Temp: 17803 K - Lux: 2699 - R: 3828 G: 5126 B: 5668 C: 14707  
Color Temp: 17784 K - Lux: 2700 - R: 3828 G: 5126 B: 5667 C: 14707  
Color Temp: 17784 K - Lux: 2700 - R: 3828 G: 5126 B: 5667 C: 14706  
Color Temp: 17784 K - Lux: 2701 - R: 3828 G: 5127 B: 5668 C: 14708  
Color Temp: 17803 K - Lux: 2699 - R: 3828 G: 5126 B: 5668 C: 14706  
Color Temp: 17787 K - Lux: 2699 - R: 3827 G: 5125 B: 5666 C: 14703  
Color Temp: 17787 K - Lux: 2699 - R: 3827 G: 5125 B: 5666 C: 14702  
Color Temp: 17789 K - Lux: 2699 - R: 3826 G: 5124 B: 5665 C: 14697  
Color Temp: 17773 K - Lux: 2699 - R: 3825 G: 5123 B: 5663 C: 14694  
Color Temp: 17794 K - Lux: 2698 - R: 3824 G: 5122 B: 5663 C: 14693  
Color Temp: 17792 K - Lux: 2697 - R: 3825 G: 5122 B: 5663 C: 14694  
Color Temp: 17814 K - Lux: 2696 - R: 3824 G: 5121 B: 5663 C: 14693  
Color Temp: 17792 K - Lux: 2698 - R: 3825 G: 5123 B: 5664 C: 14696  
Color Temp: 17795 K - Lux: 2697 - R: 3824 G: 5121 B: 5662 C: 14691  
Color Temp: 17798 K - Lux: 2695 - R: 3823 G: 5119 B: 5660 C: 14686  
Color Temp: 17798 K - Lux: 2695 - R: 3823 G: 5119 B: 5660 C: 14686  
Color Temp: 17798 K - Lux: 2695 - R: 3823 G: 5119 B: 5660 C: 14686  
Color Temp: 17797 K - Lux: 2696 - R: 3823 G: 5120 B: 5661 C: 14689  
Color Temp: 17797 K - Lux: 2696 - R: 3823 G: 5120 B: 5661 C: 14689  
Color Temp: 17797 K - Lux: 2696 - R: 3823 G: 5120 B: 5661 C: 14688  
Color Temp: 17797 K - Lux: 2696 - R: 3823 G: 5120 B: 5661 C: 14687  
Color Temp: 17797 K - Lux: 2696 - R: 3823 G: 5120 B: 5661 C: 14688  
Color Temp: 17796 K - Lux: 2696 - R: 3824 G: 5120 B: 5661 C: 14689  
Color Temp: 17779 K - Lux: 2697 - R: 3823 G: 5120 B: 5660 C: 14686  
Color Temp: 17817 K - Lux: 2695 - R: 3823 G: 5119 B: 5661 C: 14687  
Color Temp: 17797 K - Lux: 2696 - R: 3823 G: 5120 B: 5661 C: 14689  
Color Temp: 17797 K - Lux: 2696 - R: 3823 G: 5120 B: 5661 C: 14689  
Color Temp: 17797 K - Lux: 2696 - R: 3823 G: 5120 B: 5661 C: 14688  
Color Temp: 17798 K - Lux: 2695 - R: 3823 G: 5119 B: 5660 C: 14687  
Color Temp: 17800 K - Lux: 2695 - R: 3822 G: 5118 B: 5659 C: 14683  
Color Temp: 17800 K - Lux: 2696 - R: 3822 G: 5119 B: 5660 C: 14686  
Color Temp: 17795 K - Lux: 2697 - R: 3824 G: 5121 B: 5662 C: 14691  
Color Temp: 17792 K - Lux: 2697 - R: 3825 G: 5122 B: 5663 C: 14694  
Color Temp: 17811 K - Lux: 2697 - R: 3825 G: 5122 B: 5664 C: 14697  
Color Temp: 17811 K - Lux: 2697 - R: 3825 G: 5122 B: 5664 C: 14695  
Color Temp: 17792 K - Lux: 2698 - R: 3825 G: 5123 B: 5664 C: 14697  
Color Temp: 17794 K - Lux: 2698 - R: 3824 G: 5122 B: 5663 C: 14694  
Color Temp: 17792 K - Lux: 2697 - R: 3825 G: 5122 B: 5663 C: 14695  
Color Temp: 17795 K - Lux: 2697 - R: 3824 G: 5121 B: 5662 C: 14692  
Color Temp: 17798 K - Lux: 2695 - R: 3823 G: 5119 B: 5660 C: 14687  
Color Temp: 17800 K - Lux: 2696 - R: 3822 G: 5119 B: 5660 C: 14686  
Color Temp: 17800 K - Lux: 2695 - R: 3822 G: 5118 B: 5659 C: 14684  
Color Temp: 17803 K - Lux: 2694 - R: 3821 G: 5117 B: 5658 C: 14680  
Color Temp: 17787 K - Lux: 2695 - R: 3820 G: 5116 B: 5656 C: 14677  
Color Temp: 17805 K - Lux: 2694 - R: 3820 G: 5116 B: 5657 C: 14678  
Color Temp: 17787 K - Lux: 2695 - R: 3820 G: 5116 B: 5656 C: 14676  
Color Temp: 17809 K - Lux: 2692 - R: 3819 G: 5114 B: 5655 C: 14673  
Color Temp: 17809 K - Lux: 2692 - R: 3819 G: 5114 B: 5655 C: 14673  
Color Temp: 17811 K - Lux: 2692 - R: 3818 G: 5113 B: 5654 C: 14669  
Color Temp: 17795 K - Lux: 2692 - R: 3817 G: 5112 B: 5652 C: 14665  
Color Temp: 17817 K - Lux: 2690 - R: 3816 G: 5110 B: 5651 C: 14661  
Color Temp: 17797 K - Lux: 2692 - R: 3816 G: 5111 B: 5651 C: 14661  
Color Temp: 17798 K - Lux: 2691 - R: 3816 G: 5110 B: 5650 C: 14659  
Color Temp: 17781 K - Lux: 2692 - R: 3815 G: 5110 B: 5649 C: 14657  
Color Temp: 17806 K - Lux: 2688 - R: 3813 G: 5106 B: 5646 C: 14648  
Color Temp: 17806 K - Lux: 2688 - R: 3813 G: 5106 B: 5646 C: 14649  
Color Temp: 17786 K - Lux: 2690 - R: 3813 G: 5107 B: 5646 C: 14650  
Color Temp: 17803 K - Lux: 2689 - R: 3814 G: 5107 B: 5647 C: 14652  
Color Temp: 17786 K - Lux: 2690 - R: 3813 G: 5107 B: 5646 C: 14650  
Color Temp: 17806 K - Lux: 2688 - R: 3813 G: 5106 B: 5646 C: 14649  
Color Temp: 17789 K - Lux: 2689 - R: 3812 G: 5106 B: 5645 C: 14647  
Color Temp: 17808 K - Lux: 2688 - R: 3812 G: 5105 B: 5645 C: 14645  
Color Temp: 17808 K - Lux: 2688 - R: 3812 G: 5105 B: 5645 C: 14645  
Color Temp: 17811 K - Lux: 2687 - R: 3811 G: 5104 B: 5644 C: 14644  
Color Temp: 17811 K - Lux: 2687 - R: 3811 G: 5104 B: 5644 C: 14642  
Color Temp: 17792 K - Lux: 2688 - R: 3811 G: 5104 B: 5643 C: 14641  
Color Temp: 17814 K - Lux: 2686 - R: 3810 G: 5102 B: 5642 C: 14639  
Color Temp: 17797 K - Lux: 2686 - R: 3809 G: 5101 B: 5640 C: 14634  
Color Temp: 17799 K - Lux: 2686 - R: 3808 G: 5101 B: 5640 C: 14633  
Color Temp: 17797 K - Lux: 2687 - R: 3809 G: 5102 B: 5641 C: 14637  
Color Temp: 17816 K - Lux: 2685 - R: 3809 G: 5101 B: 5641 C: 14636  
Color Temp: 17797 K - Lux: 2686 - R: 3809 G: 5101 B: 5640 C: 14634  
Color Temp: 17819 K - Lux: 2685 - R: 3808 G: 5100 B: 5640 C: 14633  
Color Temp: 17780 K - Lux: 2687 - R: 3808 G: 5101 B: 5639 C: 14632  
Color Temp: 17800 K - Lux: 2686 - R: 3808 G: 5100 B: 5639 C: 14632  
Color Temp: 17820 K - Lux: 2683 - R: 3808 G: 5098 B: 5638 C: 14628  
Color Temp: 17808 K - Lux: 2682 - R: 3805 G: 5095 B: 5634 C: 14618  
Color Temp: 17810 K - Lux: 2683 - R: 3804 G: 5095 B: 5634 C: 14615  
Color Temp: 17811 K - Lux: 2682 - R: 3804 G: 5094 B: 5633 C: 14613  
Color Temp: 17813 K - Lux: 2681 - R: 3803 G: 5093 B: 5632 C: 14611  
Color Temp: 17813 K - Lux: 2681 - R: 3803 G: 5093 B: 5632 C: 14612  
Color Temp: 17794 K - Lux: 2682 - R: 3803 G: 5093 B: 5631 C: 14609  
Color Temp: 17816 K - Lux: 2681 - R: 3802 G: 5092 B: 5631 C: 14608  
Color Temp: 17797 K - Lux: 2682 - R: 3802 G: 5092 B: 5630 C: 14607  
Color Temp: 17816 K - Lux: 2680 - R: 3802 G: 5091 B: 5630 C: 14605  
Color Temp: 17799 K - Lux: 2681 - R: 3801 G: 5091 B: 5629 C: 14604  
Color Temp: 17799 K - Lux: 2681 - R: 3801 G: 5091 B: 5629 C: 14605  
Color Temp: 17797 K - Lux: 2682 - R: 3802 G: 5092 B: 5630 C: 14606  
Color Temp: 17799 K - Lux: 2681 - R: 3801 G: 5091 B: 5629 C: 14605  
Color Temp: 17797 K - Lux: 2682 - R: 3802 G: 5092 B: 5630 C: 14608  
Color Temp: 17797 K - Lux: 2682 - R: 3802 G: 5092 B: 5630 C: 14608  
Color Temp: 17797 K - Lux: 2682 - R: 3802 G: 5092 B: 5630 C: 14607  
Color Temp: 17797 K - Lux: 2682 - R: 3802 G: 5092 B: 5630 C: 14607  
Color Temp: 17797 K - Lux: 2681 - R: 3802 G: 5091 B: 5629 C: 14605
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

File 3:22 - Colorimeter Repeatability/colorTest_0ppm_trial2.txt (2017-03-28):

Color Temp: 17539 K - Lux: 2687 - R: 3801 G: 5086 B: 5610 C: 14581  
Color Temp: 17608 K - Lux: 2687 - R: 3803 G: 5090 B: 5618 C: 14594  
Color Temp: 17631 K - Lux: 2685 - R: 3801 G: 5088 B: 5617 C: 14588  
Color Temp: 17652 K - Lux: 2684 - R: 3800 G: 5087 B: 5617 C: 14587  
Color Temp: 17650 K - Lux: 2684 - R: 3801 G: 5088 B: 5618 C: 14591  
Color Temp: 17652 K - Lux: 2684 - R: 3800 G: 5087 B: 5617 C: 14588  
Color Temp: 17677 K - Lux: 2681 - R: 3798 G: 5084 B: 5615 C: 14580  
Color Temp: 17679 K - Lux: 2681 - R: 3797 G: 5083 B: 5614 C: 14576  
Color Temp: 17686 K - Lux: 2679 - R: 3794 G: 5080 B: 5611 C: 14565  
Color Temp: 17686 K - Lux: 2679 - R: 3794 G: 5080 B: 5611 C: 14566  
Color Temp: 17687 K - Lux: 2678 - R: 3794 G: 5079 B: 5610 C: 14565  
Color Temp: 17687 K - Lux: 2678 - R: 3794 G: 5079 B: 5610 C: 14565  
Color Temp: 17689 K - Lux: 2678 - R: 3793 G: 5078 B: 5609 C: 14563  
Color Temp: 17689 K - Lux: 2678 - R: 3793 G: 5078 B: 5609 C: 14563  
Color Temp: 17691 K - Lux: 2679 - R: 3792 G: 5079 B: 5610 C: 14563  
Color Temp: 17710 K - Lux: 2677 - R: 3792 G: 5078 B: 5610 C: 14563  
Color Temp: 17691 K - Lux: 2678 - R: 3792 G: 5078 B: 5609 C: 14562  
Color Temp: 17711 K - Lux: 2676 - R: 3792 G: 5077 B: 5609 C: 14562  
Color Temp: 17732 K - Lux: 2675 - R: 3791 G: 5076 B: 5609 C: 14560  
Color Temp: 17716 K - Lux: 2675 - R: 3790 G: 5075 B: 5607 C: 14556  
Color Temp: 17735 K - Lux: 2674 - R: 3790 G: 5074 B: 5607 C: 14555  
Color Temp: 17738 K - Lux: 2673 - R: 3789 G: 5073 B: 5606 C: 14553  
Color Temp: 17738 K - Lux: 2673 - R: 3789 G: 5073 B: 5606 C: 14552  
Color Temp: 17718 K - Lux: 2675 - R: 3789 G: 5074 B: 5606 C: 14554  
Color Temp: 17719 K - Lux: 2674 - R: 3789 G: 5073 B: 5605 C: 14551  
Color Temp: 17719 K - Lux: 2674 - R: 3789 G: 5073 B: 5605 C: 14552  
Color Temp: 17735 K - Lux: 2674 - R: 3790 G: 5074 B: 5607 C: 14555  
Color Temp: 17732 K - Lux: 2675 - R: 3791 G: 5076 B: 5609 C: 14560  
Color Temp: 17730 K - Lux: 2676 - R: 3792 G: 5077 B: 5610 C: 14563  
Color Temp: 17730 K - Lux: 2676 - R: 3792 G: 5077 B: 5610 C: 14562  
Color Temp: 17730 K - Lux: 2676 - R: 3792 G: 5077 B: 5610 C: 14563  
Color Temp: 17749 K - Lux: 2675 - R: 3792 G: 5077 B: 5611 C: 14564  
Color Temp: 17729 K - Lux: 2677 - R: 3792 G: 5078 B: 5611 C: 14566  
Color Temp: 17729 K - Lux: 2677 - R: 3792 G: 5078 B: 5611 C: 14565  
Color Temp: 17729 K - Lux: 2677 - R: 3792 G: 5078 B: 5611 C: 14566  
Color Temp: 17726 K - Lux: 2678 - R: 3793 G: 5080 B: 5613 C: 14569  
Color Temp: 17726 K - Lux: 2678 - R: 3793 G: 5080 B: 5613 C: 14568  
Color Temp: 17726 K - Lux: 2678 - R: 3793 G: 5080 B: 5613 C: 14568  
Color Temp: 17738 K - Lux: 2679 - R: 3796 G: 5083 B: 5617 C: 14579  
Color Temp: 17735 K - Lux: 2680 - R: 3797 G: 5085 B: 5619 C: 14584  
Color Temp: 17751 K - Lux: 2680 - R: 3798 G: 5086 B: 5621 C: 14588  
Color Temp: 17749 K - Lux: 2680 - R: 3799 G: 5087 B: 5622 C: 14591  
Color Temp: 17732 K - Lux: 2682 - R: 3798 G: 5087 B: 5621 C: 14589  
Color Temp: 17732 K - Lux: 2682 - R: 3798 G: 5087 B: 5621 C: 14589  
Color Temp: 17735 K - Lux: 2680 - R: 3797 G: 5085 B: 5619 C: 14584  
Color Temp: 17756 K - Lux: 2679 - R: 3796 G: 5084 B: 5619 C: 14583  
Color Temp: 17737 K - Lux: 2680 - R: 3796 G: 5085 B: 5619 C: 14583  
Color Temp: 17756 K - Lux: 2679 - R: 3796 G: 5084 B: 5619 C: 14581  
Color Temp: 17737 K - Lux: 2680 - R: 3796 G: 5084 B: 5618 C: 14580  
Color Temp: 17740 K - Lux: 2679 - R: 3795 G: 5083 B: 5617 C: 14578  
Color Temp: 17759 K - Lux: 2678 - R: 3795 G: 5082 B: 5617 C: 14576  
Color Temp: 17759 K - Lux: 2678 - R: 3795 G: 5082 B: 5617 C: 14576  
Color Temp: 17762 K - Lux: 2677 - R: 3794 G: 5081 B: 5616 C: 14573  
Color Temp: 17743 K - Lux: 2678 - R: 3794 G: 5081 B: 5615 C: 14573  
Color Temp: 17745 K - Lux: 2677 - R: 3793 G: 5080 B: 5614 C: 14569  
Color Temp: 17745 K - Lux: 2677 - R: 3793 G: 5080 B: 5614 C: 14570  
Color Temp: 17765 K - Lux: 2676 - R: 3793 G: 5079 B: 5614 C: 14569  
Color Temp: 17745 K - Lux: 2677 - R: 3793 G: 5080 B: 5614 C: 14570  
Color Temp: 17745 K - Lux: 2677 - R: 3793 G: 5080 B: 5614 C: 14570  
Color Temp: 17748 K - Lux: 2677 - R: 3792 G: 5079 B: 5613 C: 14567  
Color Temp: 17748 K - Lux: 2677 - R: 3792 G: 5079 B: 5613 C: 14567  
Color Temp: 17750 K - Lux: 2676 - R: 3791 G: 5078 B: 5612 C: 14564  
Color Temp: 17750 K - Lux: 2676 - R: 3791 G: 5078 B: 5612 C: 14564  
Color Temp: 17770 K - Lux: 2675 - R: 3791 G: 5077 B: 5612 C: 14563  
Color Temp: 17753 K - Lux: 2675 - R: 3790 G: 5076 B: 5610 C: 14558  
Color Temp: 17756 K - Lux: 2674 - R: 3789 G: 5075 B: 5609 C: 14557  
Color Temp: 17758 K - Lux: 2674 - R: 3788 G: 5074 B: 5608 C: 14554  
Color Temp: 17759 K - Lux: 2673 - R: 3788 G: 5073 B: 5607 C: 14552  
Color Temp: 17761 K - Lux: 2672 - R: 3787 G: 5072 B: 5606 C: 14549  
Color Temp: 17781 K - Lux: 2671 - R: 3787 G: 5071 B: 5606 C: 14547  
Color Temp: 17764 K - Lux: 2672 - R: 3786 G: 5071 B: 5605 C: 14546  
Color Temp: 17764 K - Lux: 2671 - R: 3786 G: 5070 B: 5604 C: 14543  
Color Temp: 17766 K - Lux: 2671 - R: 3785 G: 5070 B: 5604 C: 14543  
Color Temp: 17786 K - Lux: 2670 - R: 3785 G: 5069 B: 5604 C: 14542  
Color Temp: 17769 K - Lux: 2671 - R: 3784 G: 5069 B: 5603 C: 14539  
Color Temp: 17769 K - Lux: 2670 - R: 3784 G: 5068 B: 5602 C: 14538  
Color Temp: 17772 K - Lux: 2669 - R: 3783 G: 5067 B: 5601 C: 14534  
Color Temp: 17772 K - Lux: 2669 - R: 3783 G: 5067 B: 5601 C: 14534  
Color Temp: 17774 K - Lux: 2669 - R: 3782 G: 5066 B: 5600 C: 14532  
Color Temp: 17753 K - Lux: 2670 - R: 3783 G: 5067 B: 5600 C: 14532  
Color Temp: 17769 K - Lux: 2670 - R: 3784 G: 5068 B: 5602 C: 14537  
Color Temp: 17750 K - Lux: 2672 - R: 3784 G: 5069 B: 5602 C: 14538  
Color Temp: 17769 K - Lux: 2670 - R: 3784 G: 5068 B: 5602 C: 14537  
Color Temp: 17769 K - Lux: 2671 - R: 3784 G: 5069 B: 5603 C: 14538  
Color Temp: 17763 K - Lux: 2673 - R: 3786 G: 5072 B: 5606 C: 14546  
Color Temp: 17761 K - Lux: 2673 - R: 3787 G: 5073 B: 5607 C: 14549  
Color Temp: 17757 K - Lux: 2675 - R: 3788 G: 5075 B: 5609 C: 14554  
Color Temp: 17755 K - Lux: 2675 - R: 3789 G: 5076 B: 5610 C: 14558  
Color Temp: 17752 K - Lux: 2676 - R: 3790 G: 5077 B: 5611 C: 14559  
Color Temp: 17764 K - Lux: 2677 - R: 3793 G: 5080 B: 5615 C: 14569  
Color Temp: 17777 K - Lux: 2678 - R: 3795 G: 5083 B: 5619 C: 14577  
Color Temp: 17796 K - Lux: 2677 - R: 3795 G: 5083 B: 5620 C: 14579  
Color Temp: 17775 K - Lux: 2678 - R: 3796 G: 5084 B: 5620 C: 14581  
Color Temp: 17775 K - Lux: 2678 - R: 3796 G: 5084 B: 5620 C: 14581  
Color Temp: 17774 K - Lux: 2679 - R: 3796 G: 5085 B: 5621 C: 14583  
Color Temp: 17772 K - Lux: 2680 - R: 3797 G: 5086 B: 5622 C: 14587  
Color Temp: 17791 K - Lux: 2679 - R: 3797 G: 5086 B: 5623 C: 14589  
Color Temp: 17769 K - Lux: 2680 - R: 3798 G: 5087 B: 5623 C: 14591  
Color Temp: 17769 K - Lux: 2681 - R: 3798 G: 5088 B: 5624 C: 14591  
Color Temp: 17771 K - Lux: 2680 - R: 3797 G: 5087 B: 5623 C: 14590  
Color Temp: 17769 K - Lux: 2680 - R: 3798 G: 5087 B: 5623 C: 14589  
Color Temp: 17769 K - Lux: 2681 - R: 3798 G: 5088 B: 5624 C: 14591  
Color Temp: 17785 K - Lux: 2681 - R: 3799 G: 5089 B: 5626 C: 14595  
Color Temp: 17783 K - Lux: 2680 - R: 3800 G: 5089 B: 5626 C: 14597  
Color Temp: 17783 K - Lux: 2680 - R: 3800 G: 5089 B: 5626 C: 14597  
Color Temp: 17783 K - Lux: 2680 - R: 3800 G: 5089 B: 5626 C: 14598  
Color Temp: 17783 K - Lux: 2681 - R: 3800 G: 5090 B: 5627 C: 14601  
Color Temp: 17781 K - Lux: 2681 - R: 3801 G: 5090 B: 5627 C: 14604  
Color Temp: 17800 K - Lux: 2680 - R: 3801 G: 5090 B: 5628 C: 14605  
Color Temp: 17800 K - Lux: 2679 - R: 3801 G: 5089 B: 5627 C: 14604  
Color Temp: 17781 K - Lux: 2680 - R: 3801 G: 5089 B: 5626 C: 14603  
Color Temp: 17781 K - Lux: 2680 - R: 3801 G: 5089 B: 5626 C: 14604  
Color Temp: 17800 K - Lux: 2680 - R: 3801 G: 5090 B: 5628 C: 14607  
Color Temp: 17800 K - Lux: 2679 - R: 3801 G: 5089 B: 5627 C: 14604  
Color Temp: 17800 K - Lux: 2679 - R: 3801 G: 5089 B: 5627 C: 14606  
Color Temp: 17801 K - Lux: 2678 - R: 3801 G: 5088 B: 5626 C: 14604  
Color Temp: 17821 K - Lux: 2677 - R: 3801 G: 5087 B: 5626 C: 14603  
Color Temp: 17823 K - Lux: 2677 - R: 3800 G: 5087 B: 5626 C: 14602  
Color Temp: 17803 K - Lux: 2679 - R: 3800 G: 5088 B: 5626 C: 14603  
Color Temp: 17803 K - Lux: 2679 - R: 3800 G: 5088 B: 5626 C: 14602  
Color Temp: 17785 K - Lux: 2681 - R: 3799 G: 5089 B: 5626 C: 14602  
Color Temp: 17786 K - Lux: 2680 - R: 3799 G: 5088 B: 5625 C: 14599  
Color Temp: 17767 K - Lux: 2681 - R: 3799 G: 5088 B: 5624 C: 14598  
Color Temp: 17767 K - Lux: 2681 - R: 3799 G: 5088 B: 5624 C: 14598  
Color Temp: 17784 K - Lux: 2680 - R: 3800 G: 5088 B: 5625 C: 14601  
Color Temp: 17805 K - Lux: 2678 - R: 3799 G: 5087 B: 5625 C: 14598  
Color Temp: 17825 K - Lux: 2677 - R: 3799 G: 5086 B: 5625 C: 14595  
Color Temp: 17805 K - Lux: 2678 - R: 3799 G: 5087 B: 5625 C: 14594  
Color Temp: 17827 K - Lux: 2677 - R: 3798 G: 5086 B: 5625 C: 14591  
Color Temp: 17810 K - Lux: 2678 - R: 3797 G: 5086 B: 5624 C: 14590  
Color Temp: 17812 K - Lux: 2678 - R: 3796 G: 5085 B: 5623 C: 14590  
Color Temp: 17810 K - Lux: 2677 - R: 3797 G: 5085 B: 5623 C: 14592  
Color Temp: 17791 K - Lux: 2678 - R: 3797 G: 5085 B: 5622 C: 14592  
Color Temp: 17770 K - Lux: 2679 - R: 3798 G: 5086 B: 5622 C: 14595  
Color Temp: 17770 K - Lux: 2679 - R: 3798 G: 5086 B: 5622 C: 14593  
Color Temp: 17789 K - Lux: 2679 - R: 3798 G: 5086 B: 5623 C: 14593  
Color Temp: 17791 K - Lux: 2679 - R: 3797 G: 5086 B: 5623 C: 14591  
Color Temp: 17788 K - Lux: 2679 - R: 3798 G: 5087 B: 5624 C: 14592  
Color Temp: 17788 K - Lux: 2679 - R: 3798 G: 5087 B: 5624 C: 14592  
Color Temp: 17791 K - Lux: 2679 - R: 3797 G: 5086 B: 5623 C: 14590  
Color Temp: 17810 K - Lux: 2678 - R: 3797 G: 5086 B: 5624 C: 14591  
Color Temp: 17791 K - Lux: 2679 - R: 3797 G: 5086 B: 5623 C: 14590  
Color Temp: 17791 K - Lux: 2679 - R: 3797 G: 5086 B: 5623 C: 14589  
Color Temp: 17791 K - Lux: 2679 - R: 3797 G: 5086 B: 5623 C: 14589  
Color Temp: 17812 K - Lux: 2678 - R: 3796 G: 5085 B: 5623 C: 14587  
Color Temp: 17793 K - Lux: 2678 - R: 3796 G: 5085 B: 5622 C: 14587  
Color Temp: 17810 K - Lux: 2677 - R: 3797 G: 5085 B: 5623 C: 14589  
Color Temp: 17810 K - Lux: 2677 - R: 3797 G: 5085 B: 5623 C: 14588  
Color Temp: 17813 K - Lux: 2677 - R: 3796 G: 5084 B: 5622 C: 14586  
Color Temp: 17794 K - Lux: 2677 - R: 3796 G: 5084 B: 5621 C: 14584  
Color Temp: 17777 K - Lux: 2679 - R: 3795 G: 5084 B: 5620 C: 14584  
Color Temp: 17760 K - Lux: 2679 - R: 3794 G: 5083 B: 5618 C: 14579  
Color Temp: 17761 K - Lux: 2678 - R: 3794 G: 5082 B: 5617 C: 14575  
Color Temp: 17758 K - Lux: 2678 - R: 3795 G: 5083 B: 5618 C: 14577  
Color Temp: 17777 K - Lux: 2678 - R: 3795 G: 5083 B: 5619 C: 14577  
Color Temp: 17780 K - Lux: 2677 - R: 3794 G: 5082 B: 5618 C: 14573  
Color Temp: 17799 K - Lux: 2676 - R: 3794 G: 5082 B: 5619 C: 14574  
Color Temp: 17798 K - Lux: 2677 - R: 3794 G: 5083 B: 5620 C: 14576  
Color Temp: 17798 K - Lux: 2677 - R: 3794 G: 5083 B: 5620 C: 14576  
Color Temp: 17800 K - Lux: 2678 - R: 3793 G: 5083 B: 5620 C: 14575  
Color Temp: 17801 K - Lux: 2677 - R: 3793 G: 5082 B: 5619 C: 14572  
Color Temp: 17784 K - Lux: 2678 - R: 3792 G: 5082 B: 5618 C: 14571  
Color Temp: 17784 K - Lux: 2678 - R: 3792 G: 5082 B: 5618 C: 14571  
Color Temp: 17803 K - Lux: 2676 - R: 3792 G: 5081 B: 5618 C: 14570  
Color Temp: 17784 K - Lux: 2677 - R: 3792 G: 5081 B: 5617 C: 14569  
Color Temp: 17787 K - Lux: 2676 - R: 3791 G: 5080 B: 5616 C: 14568  
Color Temp: 17785 K - Lux: 2676 - R: 3792 G: 5080 B: 5616 C: 14568  
Color Temp: 17787 K - Lux: 2676 - R: 3791 G: 5079 B: 5615 C: 14566  
Color Temp: 17810 K - Lux: 2673 - R: 3790 G: 5077 B: 5614 C: 14562  
Color Temp: 17815 K - Lux: 2672 - R: 3788 G: 5075 B: 5612 C: 14556  
Color Temp: 17793 K - Lux: 2674 - R: 3789 G: 5076 B: 5612 C: 14559  
Color Temp: 17793 K - Lux: 2674 - R: 3789 G: 5076 B: 5612 C: 14560  
Color Temp: 17813 K - Lux: 2672 - R: 3789 G: 5075 B: 5612 C: 14560  
Color Temp: 17815 K - Lux: 2672 - R: 3788 G: 5075 B: 5612 C: 14559  
Color Temp: 17795 K - Lux: 2673 - R: 3788 G: 5075 B: 5611 C: 14557  
Color Temp: 17815 K - Lux: 2672 - R: 3788 G: 5074 B: 5611 C: 14557  
Color Temp: 17798 K - Lux: 2673 - R: 3787 G: 5074 B: 5610 C: 14555  
Color Temp: 17818 K - Lux: 2671 - R: 3787 G: 5073 B: 5610 C: 14554  
Color Temp: 17818 K - Lux: 2670 - R: 3787 G: 5072 B: 5609 C: 14552  
Color Temp: 17801 K - Lux: 2671 - R: 3786 G: 5072 B: 5608 C: 14550  
Color Temp: 17821 K - Lux: 2670 - R: 3786 G: 5071 B: 5608 C: 14548  
Color Temp: 17806 K - Lux: 2670 - R: 3784 G: 5070 B: 5606 C: 14544  
Color Temp: 17806 K - Lux: 2670 - R: 3784 G: 5070 B: 5606 C: 14542  
Color Temp: 17809 K - Lux: 2669 - R: 3783 G: 5068 B: 5604 C: 14539  
Color Temp: 17812 K - Lux: 2667 - R: 3782 G: 5066 B: 5602 C: 14534  
Color Temp: 17795 K - Lux: 2669 - R: 3781 G: 5066 B: 5601 C: 14532  
Color Temp: 17793 K - Lux: 2669 - R: 3782 G: 5067 B: 5602 C: 14534  
Color Temp: 17809 K - Lux: 2669 - R: 3783 G: 5068 B: 5604 C: 14538  
Color Temp: 17793 K - Lux: 2669 - R: 3782 G: 5067 B: 5602 C: 14534  
Color Temp: 17812 K - Lux: 2668 - R: 3782 G: 5067 B: 5603 C: 14535  
Color Temp: 17809 K - Lux: 2669 - R: 3783 G: 5068 B: 5604 C: 14538  
Color Temp: 17807 K - Lux: 2669 - R: 3784 G: 5069 B: 5605 C: 14541  
Color Temp: 17804 K - Lux: 2671 - R: 3785 G: 5071 B: 5607 C: 14545  
Color Temp: 17820 K - Lux: 2671 - R: 3786 G: 5072 B: 5609 C: 14549  
Color Temp: 17820 K - Lux: 2671 - R: 3786 G: 5072 B: 5609 C: 14550  
Color Temp: 17818 K - Lux: 2671 - R: 3787 G: 5073 B: 5610 C: 14552  
Color Temp: 17818 K - Lux: 2671 - R: 3787 G: 5073 B: 5610 C: 14554  
Color Temp: 17799 K - Lux: 2672 - R: 3787 G: 5073 B: 5609 C: 14552  
Color Temp: 17818 K - Lux: 2671 - R: 3787 G: 5073 B: 5610 C: 14553  
Color Temp: 17799 K - Lux: 2672 - R: 3787 G: 5073 B: 5609 C: 14551  
Color Temp: 17818 K - Lux: 2671 - R: 3787 G: 5073 B: 5610 C: 14552  
Color Temp: 17821 K - Lux: 2670 - R: 3786 G: 5071 B: 5608 C: 14548  
Color Temp: 17801 K - Lux: 2671 - R: 3786 G: 5072 B: 5608 C: 14549  
Color Temp: 17804 K - Lux: 2671 - R: 3785 G: 5071 B: 5607 C: 14546  
Color Temp: 17807 K - Lux: 2669 - R: 3784 G: 5069 B: 5605 C: 14541  
Color Temp: 17809 K - Lux: 2670 - R: 3783 G: 5069 B: 5605 C: 14539  
Color Temp: 17823 K - Lux: 2670 - R: 3785 G: 5071 B: 5608 C: 14547  
Color Temp: 17804 K - Lux: 2671 - R: 3785 G: 5071 B: 5607 C: 14546  
Color Temp: 17823 K - Lux: 2669 - R: 3785 G: 5070 B: 5607 C: 14544  
Color Temp: 17806 K - Lux: 2670 - R: 3784 G: 5070 B: 5606 C: 14543  
Color Temp: 17806 K - Lux: 2670 - R: 3784 G: 5070 B: 5606 C: 14543  
Color Temp: 17807 K - Lux: 2669 - R: 3784 G: 5069 B: 5605 C: 14541  
Color Temp: 17806 K - Lux: 2670 - R: 3784 G: 5070 B: 5606 C: 14542  
Color Temp: 17809 K - Lux: 2670 - R: 3783 G: 5069 B: 5605 C: 14539  
Color Temp: 17790 K - Lux: 2670 - R: 3783 G: 5069 B: 5604 C: 14539  
Color Temp: 17792 K - Lux: 2670 - R: 3782 G: 5068 B: 5603 C: 14536  
Color Temp: 17812 K - Lux: 2668 - R: 3782 G: 5067 B: 5603 C: 14535  
Color Temp: 17812 K - Lux: 2668 - R: 3782 G: 5067 B: 5603 C: 14534  
Color Temp: 17814 K - Lux: 2668 - R: 3781 G: 5066 B: 5602 C: 14531  
Color Temp: 17814 K - Lux: 2668 - R: 3781 G: 5066 B: 5602 C: 14531  
Color Temp: 17826 K - Lux: 2669 - R: 3784 G: 5069 B: 5606 C: 14542  
Color Temp: 17804 K - Lux: 2671 - R: 3785 G: 5071 B: 5607 C: 14545  
Color Temp: 17823 K - Lux: 2670 - R: 3785 G: 5071 B: 5608 C: 14546  
Color Temp: 17823 K - Lux: 2669 - R: 3785 G: 5070 B: 5607 C: 14545  
Color Temp: 17804 K - Lux: 2671 - R: 3785 G: 5071 B: 5607 C: 14545  
Color Temp: 17823 K - Lux: 2670 - R: 3785 G: 5071 B: 5608 C: 14547  
Color Temp: 17823 K - Lux: 2670 - R: 3785 G: 5071 B: 5608 C: 14546  
Color Temp: 17818 K - Lux: 2671 - R: 3787 G: 5073 B: 5610 C: 14553  
Color Temp: 17815 K - Lux: 2672 - R: 3788 G: 5074 B: 5611 C: 14556  
Color Temp: 17834 K - Lux: 2671 - R: 3788 G: 5074 B: 5612 C: 14556  
Color Temp: 17815 K - Lux: 2672 - R: 3788 G: 5075 B: 5612 C: 14557  
Color Temp: 17834 K - Lux: 2671 - R: 3788 G: 5074 B: 5612 C: 14557
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

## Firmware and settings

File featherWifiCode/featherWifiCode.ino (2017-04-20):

#include <Wire.h>
#include <aJSON.h>
#include "Adafruit_TCS34725.h"
#include <Adafruit_ADS1015.h>

#define LED_ID 13
#define COLOR_SENSOR_ID_1 14
#define COLOR_SENSOR_ID_2 16
#define ADC_ID 12

//#define INITIAL_WAIT 2 * 60 * 1000
//#define TOTAL_EXPERIMENT_TIME 60 * 1000

/* Initialise with default values (int time = 2.4ms, gain = 1x) */
/* Adafruit_TCS34725 tcs = Adafruit_TCS34725();
  /* Initialise with specific int time and gain values */
Adafruit_TCS34725 tcs = Adafruit_TCS34725(TCS34725_INTEGRATIONTIME_700MS, TCS34725_GAIN_1X);
Adafruit_ADS1115 ads(0x48);

void setup(void) {
  Serial.begin(115200);
  delay(100);
  // Set up digital write pins
  pinMode(LED_ID, OUTPUT);
  pinMode(COLOR_SENSOR_ID_1, OUTPUT);
  pinMode(COLOR_SENSOR_ID_2, OUTPUT);
  pinMode(ADC_ID, OUTPUT);

  Serial.println("Setup complete");
}

void loop(void) {
  if (connectToWiFi() == -1) {
    return;
  }

  aJsonObject* experimentInfo = get("/api/newExperiment");
  String experiment = getField(experimentInfo, "experimentName");

  if (experiment != "") {
    int numExperiments = getField(experimentInfo, "numExperiments").toInt();
    int initialWait = getField(experimentInfo, "initialWait").toInt();
    int totalExperimentTime = getField(experimentInfo, "totalExperimentTime").toInt();    

    createTrial(experiment);
    Serial.println("Trial created");
    Serial.println("Pausing...");
    delay(initialWait);
    Serial.println("Starting to collect data");
    digitalWrite(LED_ID, HIGH);
    delay(500);
    collectData(experiment, numExperiments, tcs, ads, totalExperimentTime);
    digitalWrite(LED_ID, LOW);
    get("/api/clearExperiment");
  }
}

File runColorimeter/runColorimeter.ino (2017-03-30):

#include <Wire.h>
#include "Adafruit_TCS34725.h"

/* Example code for the Adafruit TCS34725 breakout library */

/* Connect SCL    to analog 5
   Connect SDA    to analog 4
   Connect VDD    to 3.3V DC
   Connect GROUND to common ground */

// INITIALIZE ADAFRUIT COLOR SENSOR PARAMETERS
/* Initialise with default values (int time = 2.4ms, gain = 1x) */
// Adafruit_TCS34725 tcs = Adafruit_TCS34725();
/* Initialise with specific int time and gain values */
Adafruit_TCS34725 tcs = Adafruit_TCS34725(TCS34725_INTEGRATIONTIME_700MS, TCS34725_GAIN_1X);


// INITIALIZE LED LIGHT SOURCE
int LED_PIN = 13;

void getColorReadings(int n){
  uint16_t r, g, b, c, colorTemp, lux;
  
  tcs.getRawData(&r, &g, &b, &c);
  colorTemp = tcs.calculateColorTemperature(r, g, b);
  lux = tcs.calculateLux(r, g, b);

  for (int i = 0; i<n; i++){
    uint16_t r, g, b, c, colorTemp, lux;
  
    tcs.getRawData(&r, &g, &b, &c);
    colorTemp = tcs.calculateColorTemperature(r, g, b);
    lux = tcs.calculateLux(r, g, b);
  
    Serial.print("Color Temp: "); Serial.print(colorTemp, DEC); Serial.print(" K - ");
    Serial.print("Lux: "); Serial.print(lux, DEC); Serial.print(" - ");
    Serial.print("R: "); Serial.print(r, DEC); Serial.print(" ");
    Serial.print("G: "); Serial.print(g, DEC); Serial.print(" ");
    Serial.print("B: "); Serial.print(b, DEC); Serial.print(" ");
    Serial.print("C: "); Serial.print(c, DEC); Serial.print(" ");
    Serial.println(" ");
  
  }
  
}



void setup(void) {
  Serial.begin(115200);
  
  if (tcs.begin()) {
    Serial.println("Found sensor");
  } else {
    Serial.println("No TCS34725 found ... check your connections");
    while (1);
  }
  // turn on led
  pinMode(LED_PIN, OUTPUT);
  digitalWrite(LED_PIN, HIGH);   

  // get color reading
  getColorReadings(500);

  // turn off led
  digitalWrite(LED_PIN, LOW);   
  
}


void loop(void) {

}

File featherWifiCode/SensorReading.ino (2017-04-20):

const float PGA_VOLTS = 6144; // millivolts
const float NUM_BITS = 32767; // 2^15 - 1
const float mVOLTS_PER_BIT = PGA_VOLTS / NUM_BITS; // mV/bit

aJsonObject* takeRGBCMeasurement(Adafruit_TCS34725 tcs, Adafruit_ADS1115 ads, int sensorID) {
  // turn on sensor sensorID
  digitalWrite(sensorID, HIGH);
  delay(500);
  // Set up sensors
  Serial.print("Turning on RGB Sensor ");
  Serial.println(sensorID);
  if (tcs.begin()) {
    Serial.println("Found RGB sensor");
  } else {
    Serial.println("No TCS34725 found ... check your connections");
    while (1);
  }
  delay(500);
  uint16_t r, g, b, c, colorTemp, lux;
  // The first measurement is always all 0s, so we take 3 "warm-up" measurements
  for (int i = 0; i < 4; ++i) {
    tcs.getRawData(&r, &g, &b, &c);
    colorTemp = tcs.calculateColorTemperature(r, g, b);
    lux = tcs.calculateLux(r, g, b);
  }
  //turn off sensor sensorID
  digitalWrite(sensorID, LOW);
  return constructRGBCMeasurement(String(r), String(g), String(b), String(c), String(colorTemp), String(lux));
}
/**
   Takes a measurement from the sensor
*/
aJsonObject* takeColorMeasurement(Adafruit_TCS34725 tcs, Adafruit_ADS1115 ads) {
  return takeRGBCMeasurement(tcs, ads, COLOR_SENSOR_ID_1);
}

aJsonObject* takeTurbidityMeasurement(Adafruit_TCS34725 tcs, Adafruit_ADS1115 ads) {
  return takeRGBCMeasurement(tcs, ads, COLOR_SENSOR_ID_2);
}

aJsonObject* takeElectrochemicalMeasurement(Adafruit_TCS34725 tcs, Adafruit_ADS1115 ads) {
  Serial.println("Enabling ADS1115 sensor");
  digitalWrite(ADC_ID, HIGH);
  delay(500);
  ads.begin();

  int16_t adc0 = ads.readADC_SingleEnded(0);
  int16_t adc1 = ads.readADC_SingleEnded(1);
  int16_t adc2 = ads.readADC_SingleEnded(3);
  float aluminumVolatge = (adc0 * mVOLTS_PER_BIT) / 1000;
  float stainlessSteelVolatge = (adc1 * mVOLTS_PER_BIT) / 1000;
  float titaniumVolatge = (adc2 * mVOLTS_PER_BIT) / 1000;

  digitalWrite(ADC_ID, LOW);
  return constructElectrochemicalMeasurement(String(aluminumVolatge), String(stainlessSteelVolatge), String(titaniumVolatge));
//  return constructElectrochemicalMeasurement(String(0), String(1), String(3));
}

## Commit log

2017-02-11 added led code
2017-02-18 Adds autocad files
    [LEDHolder.dwg, SampleHolder.dwg, SensorHolder.dwg]
2017-02-23 Add files via upload
    Template which allows connection to host and transmission of color sensing data acquired by sensor system
2017-02-24 Set up the text input fields and basic GUI structure. Note that no async actions are currently happening. That is to come
2017-02-24 Sets up the text entry for the new experiment form. When all fields have been filled in, the user can press enter or press the submit button to submit the form to the server. When the form is success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
2017-02-24 Adds a field to report when the last measurement was made. Currently, just displays the time of the last dispatched action on the website
2017-02-25 Changed date to be pretty-printed
2017-02-26 Adds ability to list the measurements that the device is currently taking. Adds routing, so that now clicking on the navigation bars displays different web pages
2017-03-03 Adds skeleton for a get request to clear the current experimentInfo
2017-03-07 fixes a small bug in clearing the experiment
    [featherWifiCode.ino]
2017-03-07 Adds ability to take measurements when disconnected from wifi, and to post the measurements when the WiFi comes back up. Adds ability to collect measurements from the color sensor instead of dummy da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
2017-03-07 Adds ability to filter search for trial names
2017-03-17 Add files via upload (#7)
    Prototype BluePrints (Photoshop and PNG Files)- Dated March 16th
2017-03-17 BluePrints for Prototype
2017-03-21 PrototypeSTLFile
    Version as of March 21
    [PrototypeMarch21.stl]
2017-03-21 Add files via upload
    ColorimeterIsolatedSensor.stl
    [ColorimeterModel.stl]
2017-03-22 refactors Arduino code to remove the repeated code, and to update the post requests to the new API
2017-03-22 Sets up the framework for posting turbidity and electrochemical data
2017-03-22 Fixes a small bug in posting to the correct api endpoint
    [DataCollection.ino]
2017-03-23 Removes runtime errors produced during testing
    [DataCollection.ino, HTTPRequests.ino, featherWifiCode.ino]
2017-03-25 Adds the ability to filter trials by a query string
2017-03-26 Sets up infrastructure to take measurements from the two RGB sensors and to take measurements from the ADS1115
2017-03-27 no wifi Arduino code
2017-03-30 Adds the ability to take measurements from multiple RGB sensors, and remove errors producing all zero measurements.
    [JSONHelpers.ino, SensorReading.ino, featherWifiCode.ino]
2017-04-06 Fixes bug that caused LED to flicker while waiting for a new trial. Now, LED only turns on after a trial has been found
    [featherWifiCode.ino]
2017-04-09 Adds filter functionality for folders
2017-04-20 fixes pin
2017-04-20 fixes bug that caused script to crash
    [DataCollection.ino, featherWifiCode.ino]
